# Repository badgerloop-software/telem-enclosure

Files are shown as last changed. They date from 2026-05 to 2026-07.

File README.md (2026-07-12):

# Telemetry Enclosure

<p align="center">
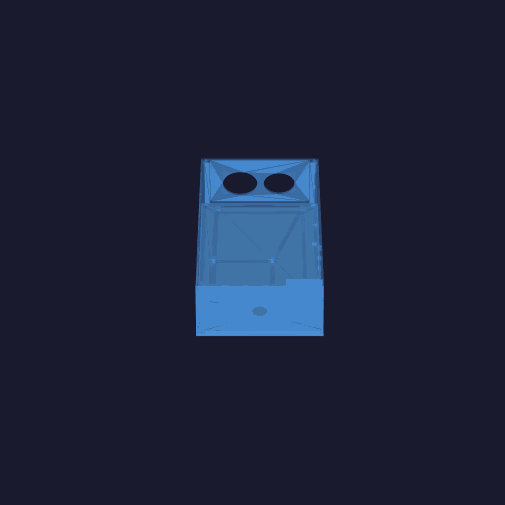
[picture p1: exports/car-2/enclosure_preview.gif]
Car 2 enclosure preview
  
</p>
3D-printable enclosure for an airborne / ground-station telemetry stack:

| Component | Notes |
|---|---|
| Raspberry Pi 4B | Bottom layer, M2.5 standoffs |
| RFD900A telemetry radio | Adhesive-mounted to left interior wall |
| Quectel EG25-G LTE module | 4× M3 wall-boss screws via Mini PCIe-to-USB adapter |
| Adafruit DS3231 RTC | Sits directly on Pi GPIO pins (no separate mount) |

| Version | Dimensions (L × W × H) | Role |
|---|---|---|
| **car-2** (active) | 228.6 × 223.5 × 57.2 mm | Working redesign — edit these exports |
| **car-1.5** (archive) | 228.6 × 223.5 × 57.2 mm | Pristine recovered SolidWorks 2023 STEP baseline |

Printable in PLA or PETG. See [`exports/README.md`](exports/README.md) for file layout.

---

## Repository layout

```
README.md                        ← you are here
telem-enclosure-components.pdf   ← component datasheets / spec reference
cad/
  import_legacy.py        ← import car-1.5 STEP → exports/car-1.5/
  analyze_step.py         ← inspect bounding boxes and hole sizes
  render_gif.py           ← turntable GIF (arg: car-1.5 or car-2)
  smooth_floor.py         ← car-2 interior floor cleanup (from car-1.5 baseline)
  update_assembly.py      ← rebuild telem_enclosure_assembly.FCStd after body/lid edits
  face_templates.py       ← 1:1 print templates (legacy compact layout)
  enclosure.py / params.py  ← experimental compact parametric model (not current car-2)
  README.md               ← design notes and print settings
exports/
  README.md               ← version layout guide
  car-1.5/                ← recovered SolidWorks archive (do not edit)
  car-2/                  ← active working folder (legacy-based redesign)
viewer/                   ← lightweight STL web viewer (face select, no FreeCAD GUI)
  server.py
  static/                 ← Three.js UI
tools/
  freecad-mcp/          ← contextform/freecad-mcp bridge for Cursor MCP
  render-venv/          ← gitignored Python venv for render_gif.py
  FreeCAD.AppImage      ← gitignored (download separately, see below)
  squashfs-root/        ← gitignored (extracted AppImage runtime)
.cursor/
  mcp.json              ← FreeCAD MCP server config for Cursor
```

## Quick start

1. **Get FreeCAD 1.0+** — either via apt or AppImage:
   ```bash
   sudo apt install freecad          # Ubuntu / Debian
   # or download the AppImage from https://freecad.org/downloads.php
   # and place it at tools/FreeCAD.AppImage
   ```

2. **Regenerate the car-1.5 archive** (only if source STEP files changed):
   ```bash
   echo 'exec(open("cad/import_legacy.py").read())' | \
     ./tools/squashfs-root/usr/bin/freecadcmd
   ```
   Reads `exports/car-1.5/SoftwareEnclosure*Car1.5.STEP`, aligns the body to
   origin, and writes `enclosure_body.{FCStd,step,stl}`, `enclosure_lid.*`, and
   `telem_enclosure_assembly.FCStd` into `exports/car-1.5/`.

3. **Work in `exports/car-2/`** — the active redesign. Copy fresh exports from
   `car-1.5/` when resetting, then edit `enclosure_body.{FCStd,step,stl}` (and lid
   as needed) in FreeCAD GUI or via the MCP bridge below.

4. **Regenerate the README preview GIF** after car-2 changes:
   ```bash
   tools/render-venv/bin/python cad/render_gif.py car-2
   ```

5. **Sync the FreeCAD assembly** after body or lid STEP/STL changes:
   ```bash
   ./tools/squashfs-root/usr/bin/freecadcmd cad/update_assembly.py car-2
   ```

See [`cad/README.md`](cad/README.md) for design notes and print settings.

## Web viewer (STL + face IDs)

A lightweight browser viewer lives in [`viewer/`](viewer/) — useful for inspecting
exports without opening FreeCAD.

```bash
python3 viewer/server.py
# open http://127.0.0.1:8765
```

| Feature | Notes |
|---|---|
| Model picker | All `exports/**/*.stl` (defaults to `car-2/enclosure_body.stl`) |
| Auto-reload | Polls file mtime every 1.5 s when STL on disk changes |
| Face IDs | First click on a flat patch assigns **#1, #2, …**; reuse when re-selected |
| Orientation | Body sits on its bottom face; **+X / +Y / +Z** axis labels on the grid |
| Save | Writes binary STL back to `exports/` (creates `.bak` first) |

**Regenerate body exports** (smooth interior floor, etc.):

```bash
./tools/squashfs-root/usr/bin/freecadcmd cad/smooth_floor.py
./tools/squashfs-root/usr/bin/freecadcmd cad/update_assembly.py car-2
```

The viewer reloads automatically when `enclosure_body.stl` changes.

## Working with Google Antigravity

Use the viewer and chat together so you can point at geometry by name:

1. **Start the viewer** (`python3 viewer/server.py`) and open the car-2 body STL.
2. **Click faces** in the model — each gets a stable number in the sidebar (e.g. **Face #2**).
3. **Tell the agent** what to change using those IDs: *“smooth face #2”*, *“remove bosses above face #3”*, etc.
4. The agent edits CAD scripts (e.g. `cad/smooth_floor.py`) or drives **FreeCAD MCP** (below), re-exports STEP/STL, and the viewer picks up the new mesh.

For live boolean edits in FreeCAD GUI, use the MCP bridge. For quick visual review and
face naming, use the web viewer — no FreeCAD window required.

## Antigravity MCP (drive FreeCAD from chat)

The repo ships a `.cursor/mcp.json` pointing to the bundled `freecad-mcp` bridge. You can add this configuration to your Antigravity setup to use it.

1. Install the Python `mcp` package (already done if you cloned this repo with the venv):
   ```bash
   cd tools/freecad-mcp && python3 -m venv .venv && .venv/bin/pip install mcp
   ```
2. In Antigravity: **add the MCP server** — a `freecad` server should appear.
3. Launch FreeCAD GUI, open `exports/car-2/enclosure_body.FCStd` or `enclosure_lid.FCStd`,
   then ask the agent to make changes; it drives FreeCAD live over the Unix socket.

## Printing

| | Body | Lid |
|---|---|---|
| Material | PETG (preferred) or PLA | PETG or PLA |
| Layer height | 0.2 mm | 0.2 mm |
| Infill | 20% gyroid | 20% gyroid |
| Walls | 3 perimeters | 3 perimeters |
| Supports | Tree — I/O cutouts only | None |
| Orientation | Open side up | Top face down |

Use M2.5 brass heat-set inserts in the Pi standoffs and lid-corner screw bosses  
for reusability. M3 × 6 mm self-tappers secure the Quectel adapter to its posts.

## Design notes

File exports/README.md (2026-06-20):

# Exports by car version

All generated model files are grouped by vehicle generation.

## `car-2/` — active redesign (work here)

| File | Description |
|---|---|
| `enclosure_body.{FCStd,step,stl}` | Body — legacy car-1.5 geometry with redesign edits |
| `enclosure_lid.{FCStd,step,stl}` | Lid copied from car-1.5 baseline |
| `telem_enclosure_assembly.FCStd` | Body + lid preview |
| `enclosure_preview.gif` | Turntable animation (shown in root README) |
| `face_templates.pdf` | Legacy 1:1 fit-check sheets (compact parametric layout; may not match) |

**Extents:** 228.6 × 223.5 × 57.2 mm (body + lid)

**Current edits:** interior floor smoothed — square pocket cutouts removed, Pi standoff
bosses and mounting holes filled (flat floor at z = 7.62 mm).

Regenerate after floor edits:
```bash
./tools/squashfs-root/usr/bin/freecadcmd cad/smooth_floor.py
./tools/squashfs-root/usr/bin/freecadcmd cad/update_assembly.py car-2
tools/render-venv/bin/python cad/render_gif.py car-2
```

**Web viewer** — inspect STL, assign face numbers for AI chat, save back to disk:
```bash
python3 viewer/server.py
# open http://127.0.0.1:8765 — select faces, reference them as #1, #2, … in Cursor
```
Auto-reload picks up STL changes when you re-export from CAD scripts. See root
[`README.md`](../README.md) for the full viewer + Cursor workflow.

**Reset from archive** (copies pristine car-1.5 exports into car-2):
```bash
cp exports/car-1.5/enclosure_body.{FCStd,step,stl} exports/car-2/
cp exports/car-1.5/enclosure_lid.{FCStd,step,stl} exports/car-2/
cp exports/car-1.5/telem_enclosure_assembly.FCStd exports/car-2/
```

## `car-1.5/` — recovered SolidWorks archive (read-only baseline)

| File | Description |
|---|---|
| `SoftwareEnclosureBottomCar1.5.STEP` | Original SolidWorks body (source) |
| `SoftwareEnclosureTopCar1.5.STEP` | Original SolidWorks lid (source) |
| `enclosure_body.{FCStd,step,stl}` | Body aligned to origin via `cad/import_legacy.py` |
| `enclosure_lid.{FCStd,step,stl}` | Lid (already origin-aligned) |
| `telem_enclosure_assembly.FCStd` | Body + lid preview |

**Extents:** 228.6 × 223.5 × 57.2 mm (body + lid)

Regenerate from source STEP:
```bash
echo 'exec(open("cad/import_legacy.py").read())' | ./tools/squashfs-root/usr/bin/freecadcmd
```

## Experimental compact parametric model

`cad/enclosure.py` builds a separate 116 × 86 mm enclosure into `exports/car-2/` if run
directly — that workflow is **not** the current car-2 redesign. Do not run it unless you
intend to replace the legacy-based exports.

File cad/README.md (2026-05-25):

# Compact Telemetry Enclosure

Parametric 3D-printable enclosure for:

- Raspberry Pi 4B
- RFD900A telemetry radio
- Quectel EG25-G LTE module (USB)
- Adafruit RTC (CR1220 onboard)

All dimensions in `cad/params.py`. The build script `cad/enclosure.py`
generates two STEP + STL files (body and lid) and an assembly preview into
`exports/`.

## Layout

```
                   +Y (back, long wall)
                   +-----------------------------+
                   | [GPIO pass-through]         |
                   |     Quectel rail + posts    |
                   |   ___________________       |
                   |  |                   |      |
    RFD900A (VHB)  |  |  Pi 4B (corner)   | Eth/ |
    on left wall → |  |  long edge along  | USB  |  +X
                   |  |  X axis           |      |
                   |  |___________________|      |
                   |                             |
                   | RTC                         |
                   +-----------------------------+
                   -Y (front long wall, HDMI/USB-C/audio cutout)
                                     |
                                  +X end (Eth + 2x USB-A cutout)
```

The Raspberry Pi sits in the +X / -Y interior corner so two of its I/O edges
are flush against the body walls.

### RFD900A mounting

The RFD900A (53 × 33 × 12 mm) has no PCB mounting holes, so it is
**adhesive-mounted** to the flat interior face of the left short wall (X = 0
inside), using VHB or double-sided foam tape. The model has no structural
features for it — the interior wall face is left smooth. Orient the board
with its antenna connectors toward the lid and U.FL cables routed up through
the lid antenna holes.

## Dimensions (default)

| Quantity | Value |
| --- | --- |
| Internal cavity | 112 x 82 x 50 mm |
| External (body+lid) | 116 x 86 x ~55.5 mm |
| Wall thickness | 2.0 mm |
| Floor thickness | 2.5 mm |
| Lid thickness | 3.0 mm |
| Pi standoff height | 12 mm (M2.5 self-tap) |
| Upper shelf height | 36 mm above interior floor |
| Antenna holes | 5 x diameter 7.0 mm (3 LTE + 2 RFD) |
| Lid corner screws | 4 x M2.5 self-tap |

> The original spec called external height of 54.5 mm. Since wall=2, floor=2.5
> and lid=3, total external height with a flush lid is `2.5 + 50 + 3 = 55.5 mm`.
> Adjust `INT_H`, `FLOOR`, or `LID` in `params.py` if you need exactly 54.5 mm.

## Generate the model

Requires FreeCAD 1.0 or later (provides `freecadcmd` and the `Part`/`Mesh`
Python modules).

```bash
freecadcmd cad/enclosure.py
```

This writes into `exports/`:

- `enclosure_body.FCStd` / `.step` / `.stl`
- `enclosure_lid.FCStd`  / `.step` / `.stl`
- `telem_enclosure_assembly.FCStd` (body + lid + transparent reference bricks
  for Pi, RFD900A, Quectel, RTC)

If you only have the FreeCAD AppImage extracted at `tools/FreeCAD.AppImage`:

```bash
./tools/FreeCAD.AppImage --console cad/enclosure.py
# or, if extracted:
./tools/squashfs-root/AppRun --console cad/enclosure.py
```

## Driving FreeCAD from Cursor (MCP)

The repo ships `.cursor/mcp.json` configured for the
[contextform/freecad-mcp](https://github.com/contextform/freecad-mcp) bridge.
Once installed at `~/tools/freecad-mcp/` you can describe changes in chat and
the agent will manipulate the live FreeCAD document over MCP. The parametric
script remains the source of truth for regenerating from scratch.

## Print settings

| Setting | Body | Lid |
| --- | --- | --- |
| Material  | PETG (preferred) / PLA  | PETG / PLA |
| Layer | 0.2 mm | 0.2 mm |
| Infill | 20% gyroid | 20% gyroid |
| Walls | 3 perimeters | 3 perimeters |
| Supports  | Tree, only for I/O wall cutouts and standoff overhang | None (print snap-lip-down) |
| Orient | Open side up | Top face down |

Use M2.5 brass heat-set inserts in the standoffs and screw bosses for
reusability; if you don't have inserts, the default 2.1 mm pilot holes are
sized for M2.5 self-tappers in PETG.

## Tweaking the design

Common edits, all in `cad/params.py`:

- Change overall size: `INT_L`, `INT_W`, `INT_H`.
- Move the Pi off the corner: edit `PI_X0_INT`, `PI_Y0_INT`.
- Swap antenna group orientation: edit `ANT_LTE_Y_OFFSET`, `ANT_RFD_Y_OFFSET`,
  spacings or counts.
- Wider GPIO pass-through: `GPIO_PASS_W`, `GPIO_PASS_H`.
- More vent slots: `SIDE_VENT_COUNT_PER_LONG_WALL`, `LID_VENT_COUNT`.

Re-run `freecadcmd cad/enclosure.py`. The script also prints a clearance
report and warns if any component would collide with the lid or shelves.

## Component — Quectel adapter (Mini PCIe-to-USB)

SUPERPLUS adapter, actual dimensions: **88.9 × 44.96 × 18.03 mm**

4 mounting holes (3.55 mm Ø):
- Centre from each short (L-end) edge: 4.775 mm
- Centre from each long (W-edge) edge: 3.775 mm

The enclosure has 4 × M3 self-tap screw posts at these positions on the upper
shelf. The adapter rests on the posts and is secured with M3 × 6 mm screws.

## Verified clearances (from current params)

The build script prints a clearance report each run. Current numbers:

| Item | Z (world, mm) | Headroom (mm) |
| --- | --- | --- |
| Pi USB-A stack top | 33.0 | — |
| Shelf rail bottom | 34.5 | 1.5 above Pi  |
| RFD900A top (on shelf) | 49.5 | 8.0 to lid |
| Quectel adapter top (on shelf) | 55.5 | 2.0 to lid |
| RFD900A vs Quectel side gap | — | 4.0 mm |

`INT_H` is 55 mm (external body height ≈ 60.5 mm including floor + lid). If
your Quectel adapter ends up taller than 18 mm, increase `INT_H` by the
difference and rebuild.

## Known limitations / future work

- Component bays use simple side rails + a 4 mm retention nib; for shipping
  use, replace with screw-mount posts to whatever holes the RFD900A and
  Quectel adapter actually expose.
- Antenna hole layout is symmetric/centered; if specific antennas need to
  avoid the lid stiffener ribs, override coordinates in
  `antenna_hole_positions_exterior()`.
- GPIO access is via lid removal plus a single 18x8 mm pass-through slot on
  the back long wall. For a real panel-mount GPIO breakout, add a dedicated
  ribbon-cable cutout on the back long wall in `params.py`.
- Lid screw bosses hang from the top of the body walls (not from the floor),
  so they clear the Pi PCB sitting in the corner. They give ~10 mm of M2.5
  thread engagement.

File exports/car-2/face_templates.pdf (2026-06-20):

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

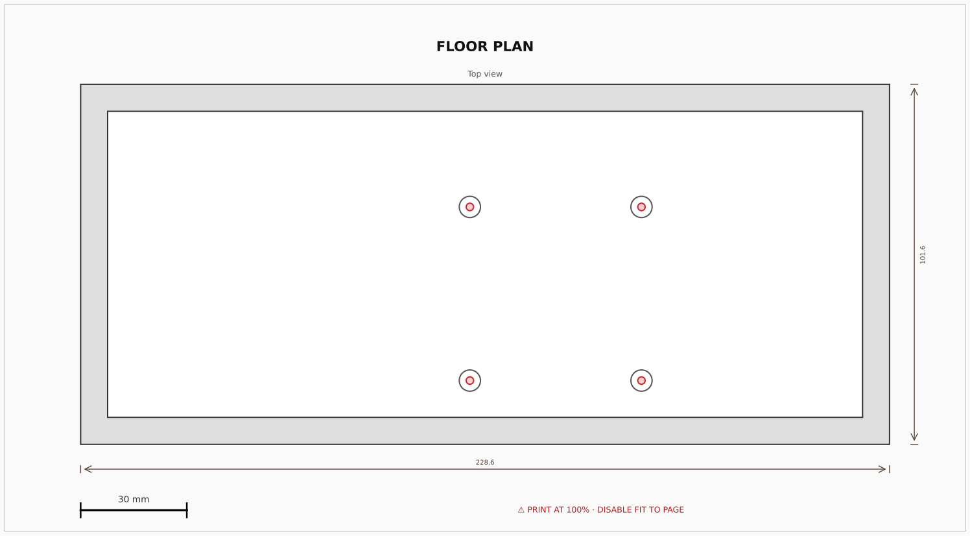
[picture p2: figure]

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

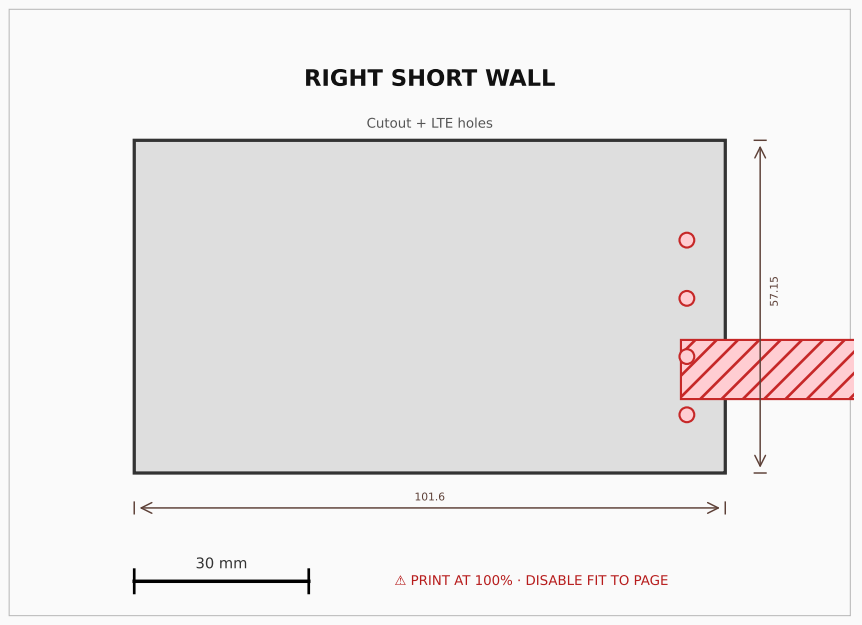
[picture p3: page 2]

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

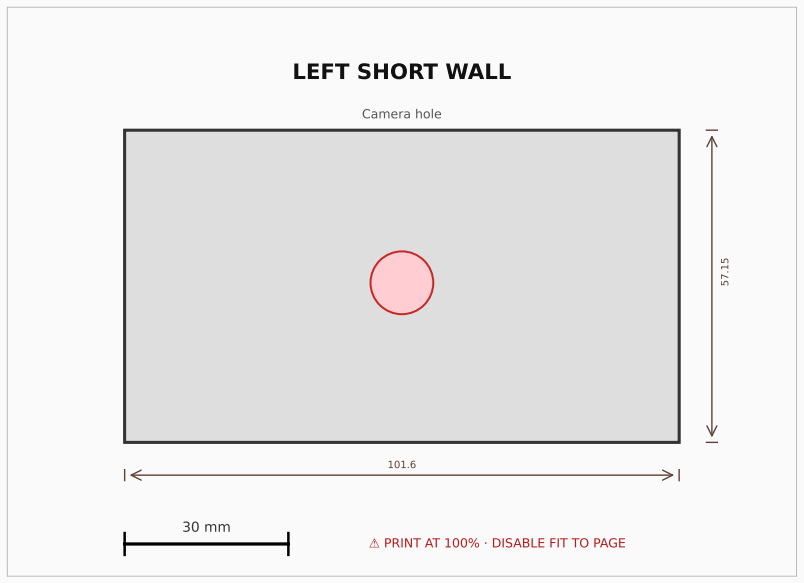
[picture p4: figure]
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

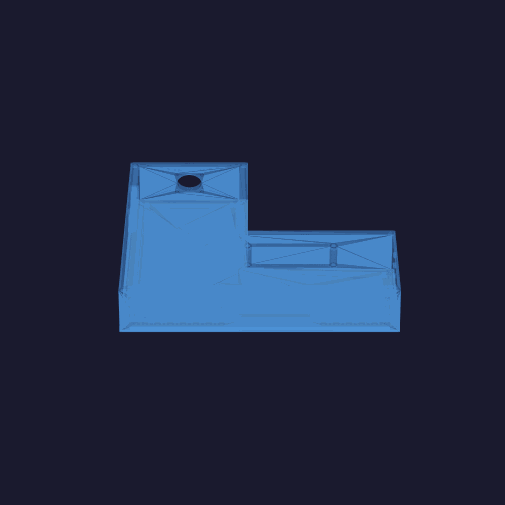
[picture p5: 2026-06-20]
preview_frame.png

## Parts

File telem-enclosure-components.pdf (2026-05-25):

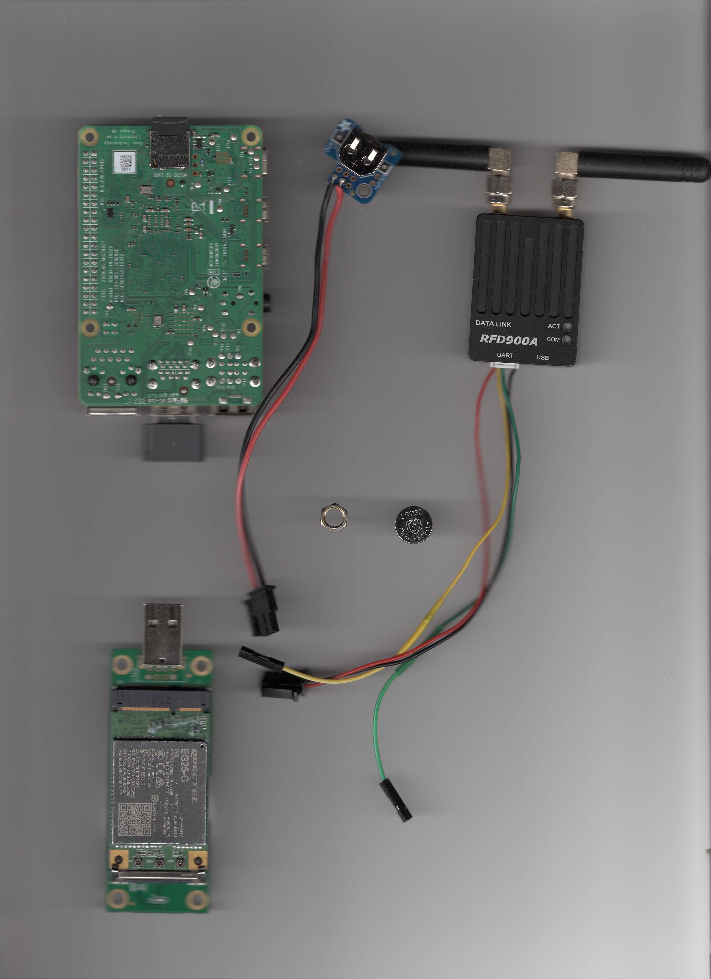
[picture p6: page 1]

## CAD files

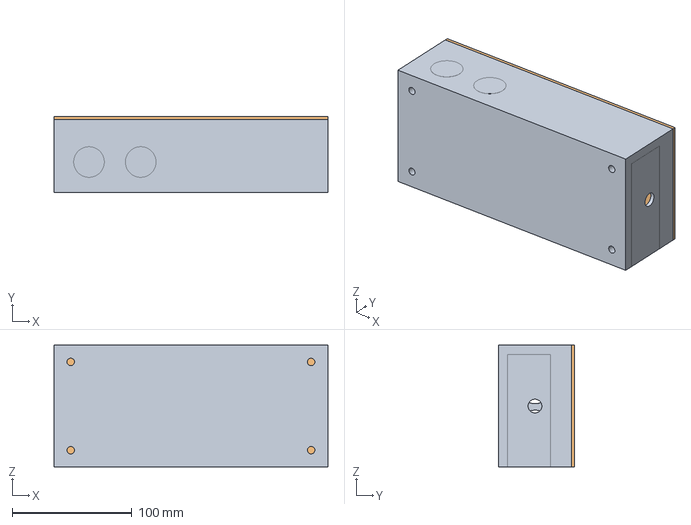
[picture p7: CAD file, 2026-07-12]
exports/car-2/telem_enclosure_assembly.FCStd
228.7 x 63.3 x 101.7 mm
Lid

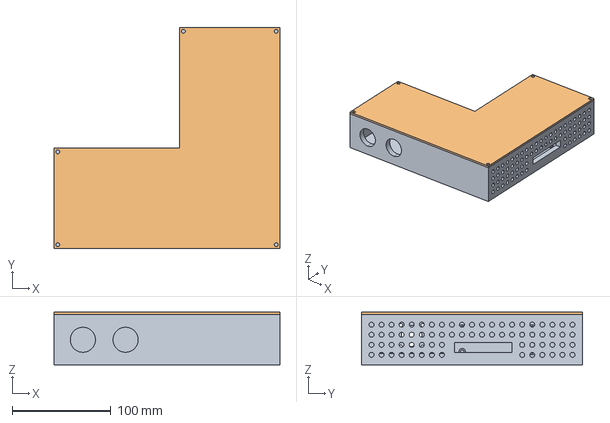
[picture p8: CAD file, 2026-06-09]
exports/car-1.5/telem_enclosure_assembly.FCStd
228.6 x 223.5 x 53.3 mm
Lid

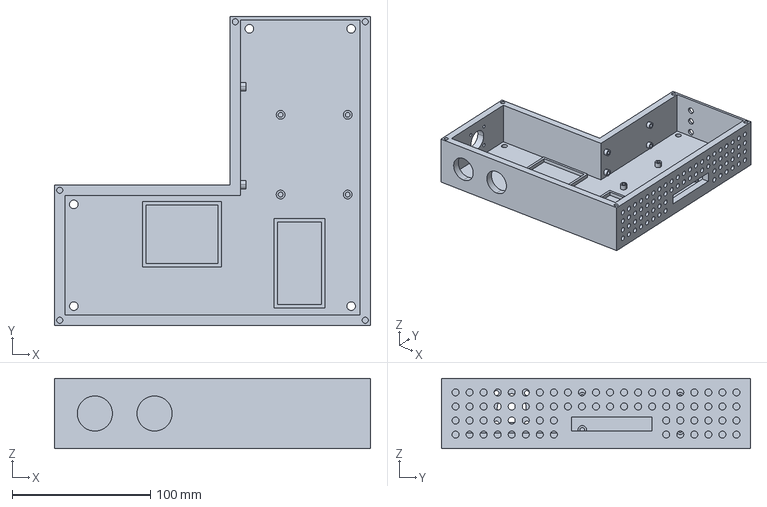
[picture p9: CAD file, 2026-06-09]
exports/car-1.5/enclosure_body.step
228.6 x 223.5 x 50.8 mm

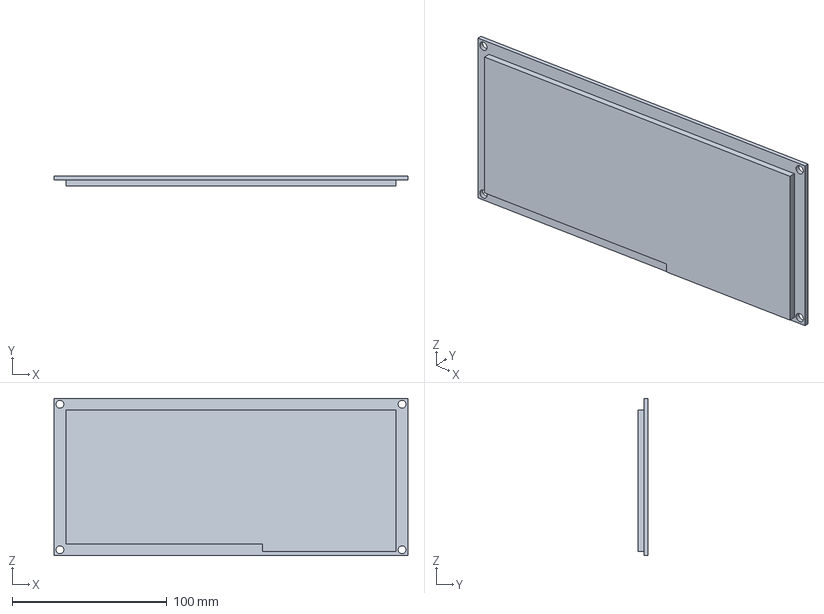
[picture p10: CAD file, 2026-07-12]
exports/car-2/enclosure_lid.step
228.6 x 6.35 x 101.6 mm

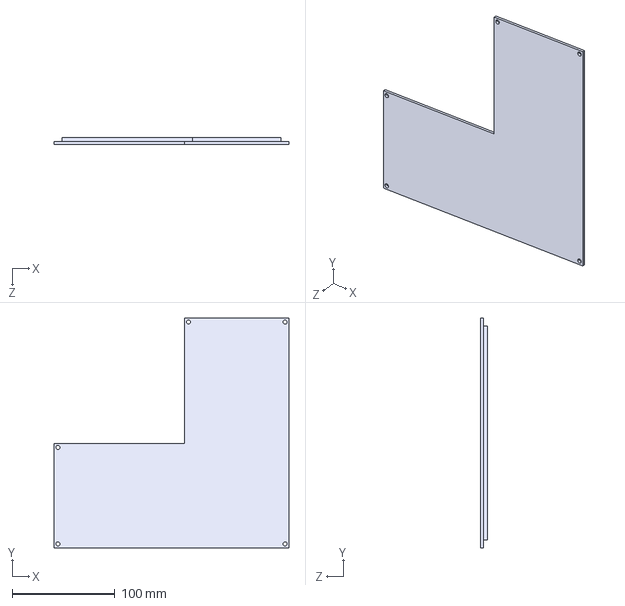
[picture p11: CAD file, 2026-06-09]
exports/car-1.5/SoftwareEnclosureTopCar1.5.STEP
228.6 x 223.5 x 6.35 mm

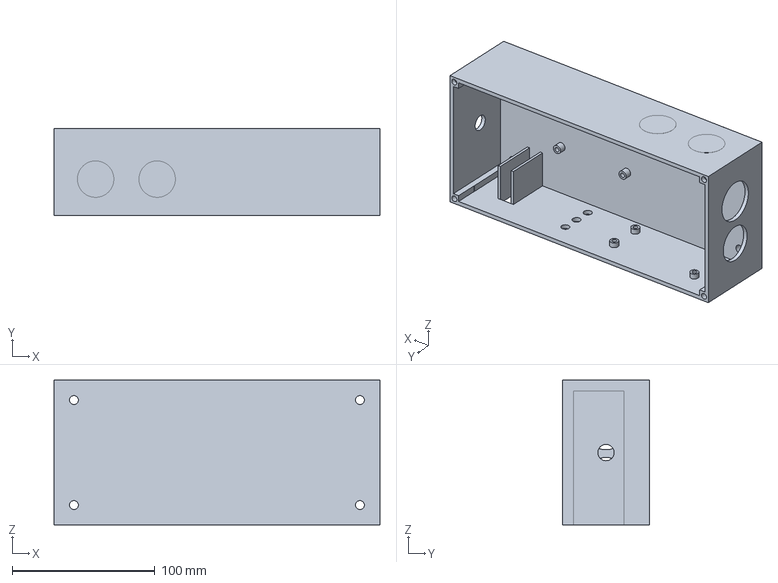
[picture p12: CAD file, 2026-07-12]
exports/car-2/enclosure_body.step
228.7 x 60.8 x 101.7 mm

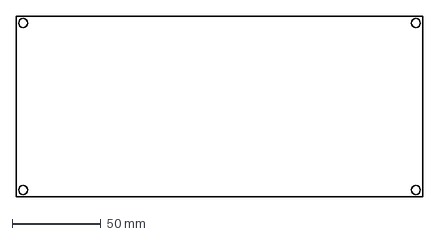
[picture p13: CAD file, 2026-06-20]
exports/car-2/enclosure_lid_flat.dxf
228.6 x 101.6 mm

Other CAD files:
exports/car-1.5/SoftwareEnclosureBottomCar1.5.STEP
exports/car-2/enclosure_body_head.stl
exports/car-1.5/enclosure_lid.step
exports/car-2/temp_relocated.step
exports/car-1.5/enclosure_body.FCStd
exports/car-1.5/enclosure_body.stl
exports/car-1.5/enclosure_lid.FCStd
exports/car-1.5/enclosure_lid.stl
exports/car-2/enclosure_body.FCStd
exports/car-2/enclosure_body.stl
exports/car-2/enclosure_lid.FCStd
exports/car-2/enclosure_lid.stl
exports/car-2/telem_enclosure_assembly.stl

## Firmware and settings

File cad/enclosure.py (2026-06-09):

"""Build the compact telemetry enclosure (body + lid) in FreeCAD.

Run headless from the project root:

    freecadcmd cad/enclosure.py

Or open FreeCAD GUI -> Macro -> open this file and run.

Outputs into ../exports/car-2 relative to this file:
    enclosure_body.FCStd, enclosure_body.step, enclosure_body.stl
    enclosure_lid.FCStd,  enclosure_lid.step,  enclosure_lid.stl
    telem_enclosure_assembly.FCStd  (body + lid + reference component bricks)
"""

from __future__ import annotations

import os
import sys
from pathlib import Path

import FreeCAD as App
import Part
import Mesh

# Make `params` importable when run via freecadcmd or exec()
try:
    HERE = Path(__file__).resolve().parent
except NameError:
    cwd = Path.cwd().resolve()
    HERE = cwd / "cad" if (cwd / "cad" / "params.py").exists() else cwd
if str(HERE) not in sys.path:
    sys.path.insert(0, str(HERE))

import params as P  # noqa: E402


EXPORT_DIR = HERE.parent / "exports" / "car-2"
EXPORT_DIR.mkdir(parents=True, exist_ok=True)


# ----------------------------------------------------------------------------
# Helpers
# ----------------------------------------------------------------------------

def _box(x, y, z, dx, dy, dz):
    """Axis-aligned box positioned at (x,y,z) with size (dx,dy,dz)."""
    b = Part.makeBox(dx, dy, dz)
    b.translate(App.Vector(x, y, z))
    return b


def _cyl(x, y, z, d, h, dir_=(0, 0, 1)):
    c = Part.makeCylinder(d / 2.0, h, App.Vector(x, y, z), App.Vector(*dir_))
    return c


def _interior_to_exterior(x, y, z):
    """Convert an interior-frame point (X in 0..INT_L, Y in 0..INT_W, Z above
    interior floor) into the body's exterior frame used by Part shapes."""
    return (x + P.WALL, y + P.WALL, z + P.FLOOR)


def _slot(x_center, y_center, z_center, length_x, length_y, length_z):
    """Centered axis-aligned box for cutouts."""
    return _box(
        x_center - length_x / 2.0,
        y_center - length_y / 2.0,
        z_center - length_z / 2.0,
        length_x,
        length_y,
        length_z,
    )


# ----------------------------------------------------------------------------
# Body
# ----------------------------------------------------------------------------

def build_body() -> Part.Shape:
    """Construct the enclosure body shell with standoffs, shelves and cutouts."""

    # Outer block, then carve cavity from the top to leave the floor.
    outer = _box(0, 0, 0, P.EXT_L, P.EXT_W, P.BODY_H)
    cavity = _box(P.WALL, P.WALL, P.FLOOR,
                  P.INT_L, P.INT_W, P.INT_H + P.LID + 1.0)
    body = outer.cut(cavity)

    # ---- Pi standoffs ----
    standoff_solids = []
    standoff_holes = []
    for ix, iy in P.pi_hole_positions_interior():
        ex, ey, _ = _interior_to_exterior(ix, iy, 0)
        standoff_solids.append(
            _cyl(ex, ey, P.FLOOR, P.STANDOFF_OD, P.STANDOFF_H)
        )
        standoff_holes.append(
            _cyl(ex, ey,
                 P.FLOOR + P.STANDOFF_H - P.STANDOFF_HOLE_DEPTH,
                 P.STANDOFF_HOLE_D,
                 P.STANDOFF_HOLE_DEPTH + P.EPS)
        )
    for s in standoff_solids:
        body = body.fuse(s)
    for h in standoff_holes:
        body = body.cut(h)

    # ---- Lid screw bosses (hang from top of body walls so they don't
    # collide with the Pi PCB sitting in the +X/-Y corner) ----
    boss_h = 10.0           # how far the boss hangs down from the wall top
    cavity_vol = _box(P.WALL, P.WALL, P.FLOOR,
                      P.INT_L, P.INT_W, P.INT_H)
    for sx, sy in P.lid_screw_positions_exterior():
        boss = _cyl(sx, sy, P.BODY_H - boss_h,
                    P.LID_SCREW_BOSS_OD, boss_h)
        boss_in = boss.common(cavity_vol)
        body = body.fuse(boss_in)
        # Self-tap pilot hole, drilled from the top
        hole = _cyl(sx, sy, P.BODY_H - boss_h - P.EPS,
                    P.LID_SCREW_BOSS_HOLE_D, boss_h + 2 * P.EPS)
        body = body.cut(hole)

    # ---- Quectel adapter: wall-mount bosses on back wall interior face ----
    # The adapter PCB sits flat against the back wall, held on 4 standoff
    # bosses (QU_MOUNT_POST_H = 3 mm) with M3 self-tap screws through the PCB.
    # Bosses project in the -Y direction from Y = WALL+INT_W.
    back_wall_y = P.WALL + P.INT_W
    for ix, iz in P.quectel_wall_hole_positions():
        ex = P.WALL + ix
        ez = P.FLOOR + iz
        boss = _cyl(ex, back_wall_y, ez,
                    P.QU_MOUNT_POST_OD, P.QU_MOUNT_POST_H, dir_=(0, -1, 0))
        body = body.fuse(boss)
        # Pilot drilled inward from the interior face (deeper than the boss)
        pilot = _cyl(ex, back_wall_y + P.EPS, ez,
                     P.QU_MOUNT_PILOT_D, P.QU_MOUNT_PILOT_DEPTH, dir_=(0, -1, 0))
        body = body.cut(pilot)

    # RTC mounts directly on Pi GPIO pins — no enclosure platform.

    # ---- Pi I/O cutout: media long edge on Y=0 wall ----
    media_z_min = P.FLOOR + P.MEDIA_CUTOUT_Z_MIN
    media_z_max = P.FLOOR + P.MEDIA_CUTOUT_Z_MAX
    media_dz = media_z_max - media_z_min
    pi_x_world = P.WALL + P.PI_X0_INT
    # Single combined slot covering USB-C through audio jack (X-range).
    media_x_min = pi_x_world + P.PI_USBC_X[0] - P.MEDIA_CUTOUT_PAD_X
    media_x_max = pi_x_world + P.PI_AUDIO_X[1] + P.MEDIA_CUTOUT_PAD_X
    media_cutout = _box(
        media_x_min, -P.EPS, media_z_min,
        media_x_max - media_x_min,
        P.WALL + 2 * P.EPS,
        media_dz,
    )
    body = body.cut(media_cutout)

    # ---- Pi I/O cutout: network short edge on X=INT_L wall (right) ----
    net_z_min = P.FLOOR + P.NET_CUTOUT_Z_MIN
    net_z_max = P.FLOOR + P.NET_CUTOUT_Z_MAX
    pi_y_world = P.WALL + P.PI_Y0_INT
    net_y_min = pi_y_world + P.PI_NETPORT_Y[0] - P.NET_CUTOUT_Y_PAD
    net_y_max = pi_y_world + P.PI_NETPORT_Y[1] + P.NET_CUTOUT_Y_PAD
    net_cutout = _box(
        P.WALL + P.INT_L - P.EPS,
        net_y_min,
        net_z_min,
        P.WALL + 2 * P.EPS,
        net_y_max - net_y_min,
        net_z_max - net_z_min,
    )
    body = body.cut(net_cutout)

    # ---- GPIO wire pass-through on X=INT_L wall (right short wall) ----
    # Sits below the Pi network/USB cutout, centered on the same Y span.
    gpio_y_world = P.WALL + P.GPIO_PASS_Y_CENTER_INT
    gpio_z_world = P.FLOOR + P.GPIO_PASS_Z
    gpio_cutout = _slot(
        P.WALL + P.INT_L + P.WALL / 2.0,  # centered through the right wall
        gpio_y_world,
        gpio_z_world,
        P.WALL + 2 * P.EPS,
        P.GPIO_PASS_W,
        P.GPIO_PASS_H,
    )
    body = body.cut(gpio_cutout)

    # ---- Side vent slots on long walls ----
    for wall_y, dir_y in [(0.0, -1.0), (P.EXT_W, 1.0)]:
        spacing = P.EXT_L / (P.SIDE_VENT_COUNT_PER_LONG_WALL + 1)
        for i in range(1, P.SIDE_VENT_COUNT_PER_LONG_WALL + 1):
            cx = i * spacing
            cz = P.FLOOR + P.SIDE_VENT_Z_CENTER
            slot = _slot(
                cx,
                wall_y + dir_y * P.WALL / 2.0,
                cz,
                P.SIDE_VENT_L,
                P.WALL + 2 * P.EPS,
                P.SIDE_VENT_W,
            )
            body = body.cut(slot)

    # ---- Left short wall (X = 0): 3 LTE + 2 RFD SMA holes + 1 CAN port ----
    # LTE — vertical stack, near back edge
    for ay_w, az_w in P.lte_left_wall_positions():
        body = body.cut(_cyl(-P.EPS, ay_w, az_w,
                             P.ANT_HOLE_D, P.WALL + 2 * P.EPS, dir_=(1, 0, 0)))
    # RFD900A — vertical stack, 20 mm apart, near front edge
    for ay_w, az_w in P.rfd_left_wall_positions():
        body = body.cut(_cyl(-P.EPS, ay_w, az_w,
                             P.ANT_HOLE_D, P.WALL + 2 * P.EPS, dir_=(1, 0, 0)))
    # CAN port — larger hole in the centre of the wall
    body = body.cut(_cyl(-P.EPS, P.CAN_HOLE_Y_WORLD, P.CAN_HOLE_Z_WORLD,
                         P.CAN_HOLE_D, P.WALL + 2 * P.EPS, dir_=(1, 0, 0)))

    # ---- Chamfer outer bottom edge for printability/feel (1 mm) ----
    try:
        edges = []
        for e in body.Edges:
            verts = e.Vertexes
            if len(verts) < 2:
                continue
            if all(abs(v.Z) < 0.01 for v in verts):
                edges.append(e)
        if edges:
            body = body.makeChamfer(1.0, edges)
    except Exception as exc:  # noqa: BLE001
        App.Console.PrintWarning(f"Skip bottom chamfer: {exc}\n")

    return body


# ----------------------------------------------------------------------------
# Lid
# ----------------------------------------------------------------------------

def build_lid() -> Part.Shape:
    """Construct the lid plate with antenna holes, snap lip and screw holes.

    The lid is built in its own coordinate frame with origin at its outer
    bottom-front-left corner. When mounted, this corner aligns with
    (0, 0, BODY_H) of the body.
    """

    plate = _box(0, 0, 0, P.EXT_L, P.EXT_W, P.LID)

    # Snap lip projecting downward from the underside of the plate.
    lip_inner = _box(
        P.WALL + P.LID_LIP_GAP,
        P.WALL + P.LID_LIP_GAP,
        -P.LID_LIP_DEPTH,
        P.INT_L - 2 * P.LID_LIP_GAP,
        P.INT_W - 2 * P.LID_LIP_GAP,
        P.LID_LIP_DEPTH,
    )
    lip_outer = _box(
        P.WALL + P.LID_LIP_GAP - P.LID_LIP_T,
        P.WALL + P.LID_LIP_GAP - P.LID_LIP_T,
        -P.LID_LIP_DEPTH,
        P.INT_L - 2 * P.LID_LIP_GAP + 2 * P.LID_LIP_T,
        P.INT_W - 2 * P.LID_LIP_GAP + 2 * P.LID_LIP_T,
        P.LID_LIP_DEPTH,
    )
    lip = lip_outer.cut(lip_inner)
    lid = plate.fuse(lip)

    # Antenna holes are on the body walls, not the lid.

    # ---- Lid screw clearance holes at corners ----
    for sx, sy in P.lid_screw_positions_exterior():
        hole = _cyl(sx, sy, -P.EPS, P.LID_SCREW_CLEAR_D, P.LID + 2 * P.EPS)
        lid = lid.cut(hole)

    # ---- Lid vent slots ----
    spacing = P.EXT_L / (P.LID_VENT_COUNT + 1)
    for i in range(1, P.LID_VENT_COUNT + 1):
        cx = i * spacing
        cy = P.EXT_W / 2.0
        slot = _slot(cx, cy, P.LID / 2.0,
                     P.LID_VENT_W, P.LID_VENT_L, P.LID + 2 * P.EPS)
        lid = lid.cut(slot)

    return lid


# ----------------------------------------------------------------------------
# Reference component bricks (for assembly preview / clearance check only)
# ----------------------------------------------------------------------------

def reference_bricks():
    """Yield (label, shape) tuples in the BODY's exterior coordinate frame."""

    # Raspberry Pi 4B (PCB + tallest top-side components, ~20mm)
    pi_x = P.WALL + P.PI_X0_INT
    pi_y = P.WALL + P.PI_Y0_INT
    pi_z = P.FLOOR + P.PI_Z0_INT
    yield (
        "RPi4B",
        _box(pi_x, pi_y, pi_z, P.PI_L, P.PI_W, P.PI_PCB_T + P.PI_USBA_H + 1.0),
    )

    # RFD900A adhered to the left short wall interior face.
    # Show it lying flat against the wall (X=WALL is the inside face).
    rfd_x = P.WALL          # against the left interior wall face
    rfd_y = P.WALL + 5.0    # 5 mm in from front
    rfd_z = P.FLOOR + 10.0  # 10 mm above floor (clear of floor fillet)
    yield ("RFD900A_on_wall", _box(rfd_x, rfd_y, rfd_z, P.RFD_H, P.RFD_W, P.RFD_L))

    # Quectel + Mini PCIe adapter — back wall, PCB face at Y = back_wall - POST_H
    qu_pcb_y = P.WALL + P.INT_W - P.QU_MOUNT_POST_H
    qu_x = P.WALL + P.QU_WALL_X0_INT
    qu_z = P.FLOOR + P.QU_WALL_Z0_INT
    # Adapter: L along X, W along Z, H extends inward (-Y direction)
    yield ("Quectel_EG25-G", _box(qu_x, qu_pcb_y - P.QU_H, qu_z, P.QU_L, P.QU_H, P.QU_W))

    # Adafruit RTC mounts on Pi GPIO pins — no separate reference brick.


# ----------------------------------------------------------------------------
# Clearance reporting
# ----------------------------------------------------------------------------

def clearance_report(body_shape):
    """Print a quick numeric clearance report against the interior cavity."""
    print("\n=== Clearance check ===")
    cavity_top_z = P.FLOOR + P.INT_H
    print(f"Interior height above floor: {P.INT_H:.1f} mm "
          f"(floor Z={P.FLOOR}, lid underside Z={cavity_top_z})")
    pi_top_z = P.FLOOR + P.PI_Z0_INT + P.PI_PCB_T + P.PI_USBA_H
    print(f"Pi USB-A stack top Z: {pi_top_z:.1f} mm "
          f"(headroom to lid: {cavity_top_z - pi_top_z:.1f} mm)")
    # Quectel on back wall: spans Z from QU_WALL_Z0_INT to QU_WALL_Z0_INT+QU_W
    qu_z_top = P.FLOOR + P.QU_WALL_Z0_INT + P.QU_W
    qu_y_front = P.WALL + P.INT_W - P.QU_MOUNT_POST_H - P.QU_H
    pi_y_max_world = P.WALL + P.PI_W
    print(f"Quectel Z span: {P.FLOOR + P.QU_WALL_Z0_INT:.1f}–{qu_z_top:.2f} mm "
          f"(headroom: {cavity_top_z - qu_z_top:.2f} mm)")
    print(f"Quectel front face Y: {qu_y_front:.2f} mm, Pi Y edge: {pi_y_max_world:.1f} mm, "
          f"gap: {qu_y_front - pi_y_max_world:.2f} mm")
    if qu_y_front < pi_y_max_world:
        print("WARNING: Quectel front face overlaps Pi PCB in Y — increase INT_W or reduce QU_H.")
    if qu_z_top > cavity_top_z:
        print("WARNING: Quectel taller than interior. Increase INT_H.")
    rfd_wall_top_z = P.FLOOR + 10.0 + P.RFD_L
    print(f"RFD900A on left wall top Z: {rfd_wall_top_z:.1f} mm (adhesive, no structural feature)")
    print(f"LTE holes (left wall, back corner): {P.lte_left_wall_positions()}")
    print(f"RFD holes (left wall, front corner): {P.rfd_left_wall_positions()}")
    print(f"CAN hole (left wall, centre): Y={P.CAN_HOLE_Y_WORLD} Z={P.CAN_HOLE_Z_WORLD:.2f} D={P.CAN_HOLE_D}mm")
    print("=======================\n")


# ----------------------------------------------------------------------------
# Build and export
# ----------------------------------------------------------------------------

def _save_step(shape, path: Path):
    shape.exportStep(str(path))


def _save_stl(shape, path: Path):
    """Tessellate to mesh and export STL."""
    mesh = Mesh.Mesh()
    mesh.addFacets(shape.tessellate(0.1))
    mesh.write(str(path))


def main():
    body = build_body()
    lid = build_lid()

    clearance_report(body)

    # ---- Body document ----
    body_doc = App.newDocument("enclosure_body")
    body_obj = body_doc.addObject("Part::Feature", "Body")
    body_obj.Shape = body
    body_doc.recompute()
    body_doc.saveAs(str(EXPORT_DIR / "enclosure_body.FCStd"))
    _save_step(body, EXPORT_DIR / "enclosure_body.step")
    _save_stl(body, EXPORT_DIR / "enclosure_body.stl")
    App.closeDocument(body_doc.Name)

    # ---- Lid document ----
    lid_doc = App.newDocument("enclosure_lid")
    lid_obj = lid_doc.addObject("Part::Feature", "Lid")
    lid_obj.Shape = lid
    lid_doc.recompute()
    lid_doc.saveAs(str(EXPORT_DIR / "enclosure_lid.FCStd"))
    _save_step(lid, EXPORT_DIR / "enclosure_lid.step")
    _save_stl(lid, EXPORT_DIR / "enclosure_lid.stl")
    App.closeDocument(lid_doc.Name)

    # ---- Assembly preview (body + lid translated up + reference bricks) ----
    asm = App.newDocument("telem_enclosure_assembly")
    body_a = asm.addObject("Part::Feature", "Body")
    body_a.Shape = body

    lid_placed = lid.copy()
    lid_placed.translate(App.Vector(0, 0, P.BODY_H))
    lid_a = asm.addObject("Part::Feature", "Lid")
    lid_a.Shape = lid_placed

    for label, brick in reference_bricks():
        ref = asm.addObject("Part::Feature", f"REF_{label}")
        ref.Shape = brick
        # ViewObject only exists when the GUI is loaded; ignore in headless.
        view = getattr(ref, "ViewObject", None)
        if view is not None:
            try:
                view.Transparency = 70
            except Exception:  # noqa: BLE001
                pass

    asm.recompute()
    asm.saveAs(str(EXPORT_DIR / "telem_enclosure_assembly.FCStd"))
    App.closeDocument(asm.Name)

    print("\nWrote outputs to:", EXPORT_DIR)
    for p in sorted(EXPORT_DIR.iterdir()):
        print("  ", p.name, f"({p.stat().st_size // 1024} KB)")


if __name__ == "__main__":
    main()

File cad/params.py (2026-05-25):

"""Parametric dimensions for the compact telemetry enclosure.

All units are millimetres. Coordinate frame for the body:
    Origin at the OUTER bottom-front-left corner.
    +X = long axis (length)
    +Y = short axis (width)
    +Z = up (toward the lid)

The interior cavity therefore starts at (WALL, WALL, FLOOR) and ends at
(WALL + INT_L, WALL + INT_W, FLOOR + INT_H).

Edit any constant here and re-run `freecadcmd cad/enclosure.py` to regenerate
the model and STEP/STL exports.
"""

# ---------- Internal volume ----------
INT_L = 112.0   # X length, inside
INT_W = 82.0    # Y width, inside
INT_H = 55.0    # Z height, inside (floor top to lid underside)
                # Bumped from 50 → 55 to clear the 18 mm tall Quectel adapter

# ---------- Wall thicknesses ----------
WALL = 2.0      # side walls
FLOOR = 2.5     # bottom plate
LID = 3.0       # lid plate

# ---------- Derived externals ----------
EXT_L = INT_L + 2 * WALL    # 116
EXT_W = INT_W + 2 * WALL    # 86
BODY_H = FLOOR + INT_H      # 52.5 (without lid)
EXT_H = BODY_H + LID        # 55.5

# ---------- Raspberry Pi 4B ----------
PI_L = 85.6
PI_W = 56.5
PI_PCB_T = 1.5

# Pi 4B mounting hole pattern (4 holes, M2.5)
PI_HOLE_DX = 58.0           # along long edge
PI_HOLE_DY = 49.0           # along short edge
PI_HOLE_OFFSET = 3.5        # from each PCB edge to hole center

# Pi standoff geometry
STANDOFF_H = 12.0
STANDOFF_OD = 6.0
STANDOFF_HOLE_D = 2.1       # self-tap pilot for M2.5; use 3.6 for heat-set
STANDOFF_HOLE_DEPTH = 9.0

# Pi placement in the +X / -Y interior corner.
# Local-interior origin is (0,0,0) at the inside floor / front-left.
# Pi long edge along X. Pi short edge against X=INT_L (right short wall).
# Pi media long edge against Y=0 (front long wall).
PI_X0_INT = INT_L - PI_L    # 26.4 (x-coord of Pi's left short edge, inside)
PI_Y0_INT = 0.0             # Pi's media edge flush with front wall
PI_Z0_INT = STANDOFF_H      # Pi PCB bottom Z (above interior floor)

# ---------- Pi 4B I/O port positions (Pi-local, 0,0 at media/USB-C corner) ----------
# Long media edge ports (Pi_y == 0): cutout on the body's Y=0 wall.
PI_USBC_X    = (3.5, 13.0)
PI_HDMI0_X   = (20.0, 32.0)
PI_HDMI1_X   = (36.5, 48.5)
PI_AUDIO_X   = (52.5, 65.0)

# Network short edge ports (Pi_x == PI_L): cutout on the body's X=INT_L wall.
# Pi 4B has Ethernet + 2 USB-A stacks across the full short edge; one
# generous slot covers all three regardless of exact arrangement.
PI_NETPORT_Y = (1.5, 56.0)

# Port heights above PCB top
PI_USBA_H = 17.0
PI_ETH_H = 14.0
PI_HDMI_H = 6.5
PI_USBC_H = 3.5
PI_AUDIO_H = 6.5

# Z reference: top of Pi PCB above the interior floor
PCB_TOP_Z = PI_Z0_INT + PI_PCB_T  # 13.5

# ---------- I/O cutouts (interior coordinates, Z above interior floor) ----------
# Slight clearance around port footprints.
MEDIA_CUTOUT_Z_MIN = PCB_TOP_Z - 1.0    # 12.5
MEDIA_CUTOUT_Z_MAX = PCB_TOP_Z + 8.0    # 21.5
MEDIA_CUTOUT_PAD_X = 1.5                 # extra each side per port group

NET_CUTOUT_Z_MIN = PCB_TOP_Z - 1.0      # 12.5
NET_CUTOUT_Z_MAX = PCB_TOP_Z + 19.0     # 32.5
NET_CUTOUT_Y_PAD = 1.5

# GPIO wire pass-through — right short wall (X=INT_L), below the Pi I/O cutout.
# Centered on the same Y range as the Pi network port cutout, near the floor.
GPIO_PASS_W = 18.0
GPIO_PASS_H = 8.0
GPIO_PASS_Z = 6.0                        # interior Z of slot center (world Z = 8.5 mm)
GPIO_PASS_Y_CENTER_INT = (PI_NETPORT_Y[0] + PI_NETPORT_Y[1]) / 2.0  # ≈ 28.75 mm

# ---------- Vent slots ----------
SIDE_VENT_W = 2.0
SIDE_VENT_L = 30.0
SIDE_VENT_COUNT_PER_LONG_WALL = 4
SIDE_VENT_Z_CENTER = 40.0       # near the top of the cavity

LID_VENT_W = 2.0
LID_VENT_L = 20.0
LID_VENT_COUNT = 6

# ---------- Components ----------
# RFD900A — no PCB mounting holes, adhesive (VHB) to interior of left short wall
RFD_L = 53.0
RFD_W = 33.0
RFD_H = 12.0

# Mini PCIe-to-USB adapter (SUPERPLUS, 3.5" x 1.77" x 0.71")
# Mounted flat against the interior face of the back long wall (Y=INT_W).
# L runs along X, W runs along Z, H is the depth into the enclosure interior.
QU_L = 88.9     # 3.5 inches — runs along X
QU_W = 44.96    # 1.77 inches — runs along Z
QU_H = 18.03    # 0.71 inches — depth away from wall (into interior)

# Mounting holes: 3.55 mm dia, M3 self-tap bosses
# Center from each short (L-end) edge: 3 + hole_r = 4.775 mm  (along X)
# Center from each long  (W-edge) edge: 2 + hole_r = 3.775 mm  (along Z)
QU_HOLE_D = 3.55
QU_HOLE_FROM_L_END = 4.775
QU_HOLE_FROM_W_EDGE = 3.775
QU_MOUNT_POST_OD = 7.0
QU_MOUNT_POST_H = 3.0    # standoff height projecting from back wall face
QU_MOUNT_PILOT_D = 3.1   # M3 self-tap pilot in PETG
QU_MOUNT_PILOT_DEPTH = 8.0

# Quectel position on back wall (interior coords: left edge X, bottom edge Z)
QU_WALL_X0_INT = 10.0    # 10 mm from left interior wall
QU_WALL_Z0_INT = 8.0     # 8 mm above interior floor

# RTC sits directly on the Pi's GPIO pins — no enclosure platform needed.
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

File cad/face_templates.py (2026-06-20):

#!/usr/bin/env python3
from pathlib import Path
import matplotlib
matplotlib.use("Agg")
import matplotlib.pyplot as plt
from matplotlib.patches import Rectangle, Circle, FancyBboxPatch
from matplotlib.backends.backend_pdf import PdfPages

EXPORTS = Path(__file__).resolve().parent.parent / "exports" / "car-2"

# Page layout
MARGIN_X, MARGIN_Y, HDR, FTR = 22, 18, 14, 16
WALL_FC, WALL_EC = "#DEDEDE", "#333333"
CAVITY_FC = "#FFFFFF"
CUT_FC, CUT_EC = "#FFCDD2", "#C62828"
DIM_C, WARN_C = "#5D4037", "#B71C1C"

def _r(ax, x, y, w, h, fc=CAVITY_FC, ec=WALL_EC, lw=0.8, ls='-', hatch=None):
    kw = dict(facecolor=fc, edgecolor=ec, linewidth=lw, linestyle=ls)
    if hatch: kw['hatch'] = hatch
    ax.add_patch(Rectangle((x, y), w, h, **kw))

def _c(ax, cx, cy, d, fc=CUT_FC, ec=CUT_EC, lw=0.8):
    ax.add_patch(Circle((cx, cy), d / 2, facecolor=fc, edgecolor=ec, linewidth=lw))

def _txt(ax, x, y, text, size=4.5, color='#333', ha='center', va='center', **kw):
    ax.text(x, y, text, fontsize=size, color=color, ha=ha, va=va, **kw)

def _dim_h(ax, x1, x2, y, label):
    ax.annotate('', xy=(x2, y), xytext=(x1, y), arrowprops=dict(arrowstyle='<->', color=DIM_C, lw=0.55))
    for xp in (x1, x2): ax.plot([xp, xp], [y-1, y+1], color=DIM_C, lw=0.55)
    _txt(ax, (x1+x2)/2, y+1.8, label, size=4, color=DIM_C)

def _dim_v(ax, x, y1, y2, label):
    ax.annotate('', xy=(x, y2), xytext=(x, y1), arrowprops=dict(arrowstyle='<->', color=DIM_C, lw=0.55))
    for yp in (y1, y2): ax.plot([x-1, x+1], [yp, yp], color=DIM_C, lw=0.55)
    _txt(ax, x+2.5, (y1+y2)/2, label, size=4, color=DIM_C, rotation=90, rotation_mode='anchor', ha='left')

def _scale_bar(ax, x, y, length=30):
    ax.plot([x, x+length], [y, y], 'k-', lw=1.3)
    for xp in (x, x+length): ax.plot([xp, xp], [y-2, y+2], 'k-', lw=1.0)
    _txt(ax, x+length/2, y+3, f'{length} mm', size=5.5)

def make_page(pdf, title, subtitle, face_w, face_h, draw_fn):
    total_w = face_w + 2*MARGIN_X
    total_h = face_h + HDR + FTR + MARGIN_Y
    fig, ax = plt.subplots(figsize=(total_w/25.4, total_h/25.4))
    ax.set_aspect('equal')
    ax.axis('off')
    ax.set_xlim(0, total_w)
    ax.set_ylim(0, total_h)
    fig.patch.set_facecolor('#FAFAFA')
    ax.add_patch(FancyBboxPatch((0.5, 0.5), total_w-1, total_h-1, boxstyle="square,pad=0", edgecolor='#BBB', facecolor='none', lw=0.4))
    ox = MARGIN_X
    oy = FTR + MARGIN_Y/2
    draw_fn(ax, ox, oy, face_w, face_h)
    _txt(ax, total_w/2, oy+face_h+HDR*0.75, title, size=8.5, color='#111', fontweight='bold')
    _txt(ax, total_w/2, oy+face_h+HDR*0.2, subtitle, size=5, color='#555')
    _scale_bar(ax, MARGIN_X, FTR*0.4, 30)
    _txt(ax, total_w*0.62, FTR*0.4, "⚠ PRINT AT 100% · DISABLE FIT TO PAGE", size=5, color=WARN_C, ha='center')
    pdf.savefig(fig)
    plt.close(fig)

# DIMS
EXT_L = 228.6
EXT_W = 101.6
BODY_H = 57.15
WALL = 7.62

def draw_floor(ax, ox, oy, fw, fh):
    _r(ax, ox, oy, fw, fh, fc=WALL_FC)
    _r(ax, ox+WALL, oy+WALL, EXT_L-2*WALL, EXT_W-2*WALL, fc=CAVITY_FC)
    # Pi holes
    PI = [(110.0, 18.0), (110.0, 67.0), (158.5, 18.0), (158.5, 67.0)]
    for px, py in PI:
        _c(ax, ox+px, oy+py, 2.1)
        _c(ax, ox+px, oy+py, 6.0, fc='none', ec="#555")
    _dim_h(ax, ox, ox+fw, oy-7, f"{fw}")
    _dim_v(ax, ox+fw+7, oy, oy+fh, f"{fh}")

def draw_right_wall(ax, ox, oy, fw, fh):
    _r(ax, ox, oy, fw, fh, fc=WALL_FC)
    _r(ax, ox, oy, fw, fh, fc='none', ec=WALL_EC, lw=1.2)
    # Cutout
    _r(ax, ox+93.98, oy+12.7, 152.4-93.98, 22.86-12.7, fc=CUT_FC, ec=CUT_EC, hatch='///')
    # LTE bosses
    for iz in [10, 20, 30, 40]:
        _c(ax, ox+95.0, oy+iz, 2.54)
    _dim_h(ax, ox, ox+fw, oy-6, f"{fw}")
    _dim_v(ax, ox+fw+6, oy, oy+fh, f"{fh}")

def draw_left_wall(ax, ox, oy, fw, fh):
    _r(ax, ox, oy, fw, fh, fc=WALL_FC)
    _r(ax, ox, oy, fw, fh, fc='none', ec=WALL_EC, lw=1.2)
    # Camera hole
    _c(ax, ox+50.8, oy+29.21, 11.5)
    _dim_h(ax, ox, ox+fw, oy-6, f"{fw}")
    _dim_v(ax, ox+fw+6, oy, oy+fh, f"{fh}")

def main():
    EXPORTS.mkdir(parents=True, exist_ok=True)
    out = EXPORTS / "face_templates.pdf"
    with PdfPages(out) as pdf:
        make_page(pdf, "FLOOR PLAN", "Top view", EXT_L, EXT_W, draw_floor)
        make_page(pdf, "RIGHT SHORT WALL", "Cutout + LTE holes", EXT_W, BODY_H, draw_right_wall)
        make_page(pdf, "LEFT SHORT WALL", "Camera hole", EXT_W, BODY_H, draw_left_wall)
    print(f"Saved {out}")

if __name__ == "__main__":
    main()

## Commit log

2026-05-25 Initial parametric enclosure model
    FreeCAD Python model (cad/enclosure.py + cad/params.py) for a compact
    telemetry enclosure housing RPi 4B, RFD900A, Quectel EG25-G + Mini PCIe
    USB adapter, and Adafruit DS3231 RTC.
    - 116 x 86 x 60.5 mm external (body + lid)
    - Pi 4B in +X/-Y corner, M2.5 standoffs, I/O cutouts on two walls
    - Quectel adapter on upper shelf with 4x M3 screw posts (correct 88.9x44.96x18.03 mm dims)
    - RFD900A adhesive-mounted to left interior wall (no PCB holes)
    - 5 antenna holes on lid (3 LTE + 2 RFD900A), snap-fit lip, 4-corner screws
    - Vent slots on lid and long side walls
    - Exports: STEP + STL for body and lid, assembly FCStd with reference bricks
    - FreeCAD MCP bridge wired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
    [enclosure_body.FCStd, enclosure_body.step, enclosure_body.stl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]
2026-05-25 Move Quectel to back wall, antenna holes to side walls
    - Quectel Mini PCIe adapter: removed floor-standing posts (clashed with
    Pi standoffs); now mounts on 4 x M3 bosses on the back wall interior
    face (QU_WALL_X0_INT=10, QU_WALL_Z0_INT=8, 3mm standoffs, 8mm pilots).
    7.5mm Y gap to Pi edge, 2mm Z headroom under lid.
    - RFD900A: already adhesive-mounted to left short wall; removed
    shelf rail remnant entirely.
    - Antenna holes moved from lid to walls:
    3 x LTE on back long wall at X=[8,26,44] world, Z=30.5mm
    2 x RFD on left short wall at Y=[34,52] world, Z=30.5mm
    Lid is now a clean plate (snap lip + corner screws + vent slots only).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
    [enclosure_body.FCStd, enclosure_body.step, enclosure_body.stl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]
2026-05-25 Remove RTC platform, consolidate antenna holes, move GPIO slot
    - Remove Adafruit RTC clip-down pad and posts; RTC now mounts on Pi GPIO pins.
    - All 5 antenna holes moved to the left short wall (X=0):
    Y = 15, 29, 43, 57, 71 mm (14 mm spacing, 11.5 mm edge margins)
    Z = 30.5 mm world — same height, 11.5 mm below vent slots
    First 3 = LTE (Quectel), last 2 = RFD (RFD900A)
    - GPIO wire pass-through relocated from back long wall to right short wall
    (X=INT_L), below the Pi network/USB cutout, at Z = 8.5 mm world.
    [enclosure_body.FCStd, enclosure_body.step, enclosure_body.stl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]
2026-05-25 Rearrange left wall: LTE/RFD vertical stacks + CAN port
    Left short wall (X=0) now has three distinct zones:
    - Back corner (Y=74mm): 3 LTE holes, vertically stacked at Z=15, 30, 45mm
    - Front corner (Y=10mm): 2 RFD900A SMA holes, 20mm c-c at Z=18.75, 38.75mm
    - Centre (Y=43mm): 1x 20mm CAN port hole at Z=28.75mm
    [enclosure_body.FCStd, enclosure_body.step, enclosure_body.stl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]
2026-05-25 Add turntable GIF preview, component PDF, and render script
    - exports/enclosure_preview.gif: 40-frame animated turntable (cad/render_gif.py)
    - Embed GIF at top of README.md for instant GitHub preview
    - Add telem-enclosure-components.pdf (component datasheets / spec reference)
    - Add cad/render_gif.py: reproducible renderer using matplotlib + numpy-stl
    - Update .gitignore to exclude tools/render-venv/
    - Fix stale RTC and Quectel mounting notes in README component table
    [render_gif.py]
2026-05-25 Add 1:1 scale face-template PDF for physical component fit-checking
    - cad/face_templates.py: generates exports/face_templates.pdf (5 pages)
    - Each page is a true 1:1 orthographic projection of one enclosure face
    - Pages: floor plan, right short wall, left short wall, front long wall,
    back long wall (interior face)
    - Shows Pi standoff holes, IO cutouts, antenna holes, Quectel boss positions
    - Dimension callouts, 30mm scale bar, and print-at-100% warning on every page
    - Regenerate with: tools/render-venv/bin/python cad/face_templates.py
    [face_templates.py]
2026-06-09 Reorganize exports by car version and add car-1.5 CAD workflow
    - Split exports into car-1.5/ (recovered SolidWorks STEP) and car-2/ (parametric)
    - Add import_legacy.py, axis-based feature extraction, and car-1.5 face templates
    - Fix face-template hole classification (axis direction + exterior wall snapping)
    - Update render_gif, face_templates, and enclosure.py for versioned export paths
    [SoftwareEnclosureBottomCar1.5.STEP, SoftwareEnclosureTopCar1.5.STEP, enclosure_body.FCStd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]
2026-06-09 Remove car-1.5 face templates and related extraction scripts
    Drop the inaccurate car-1.5 PDF blueprint and its custom generator/extractor
    scripts; car-1.5 CAD assets remain in exports/car-1.5/.
2026-06-14 Reset car-2 exports from car-1.5 baseline with smooth interior floor.
    Copy the legacy enclosure into car-2, remove rectangular floor cutouts while keeping Pi mounting holes, and refresh the README preview GIF.
    [enclosure_body.FCStd, enclosure_body.step, enclosure_body.stl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]
2026-06-14 Update READMEs to reflect car-2 as the active legacy-based redesign.
    Document car-2 as the working 228.6 mm export folder, car-1.5 as the archive baseline, and the correct GIF/MCP workflow.
2026-06-20 Add STL web viewer and sync car-2 smooth-floor exports.
    Introduces a lightweight Three.js viewer with face IDs for AI-assisted edits,
    documents the Cursor workflow, and regenerates car-2 body/assembly assets plus the preview GIF.
    [enclosure_body.FCStd, enclosure_body.step, enclosure_body.stl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]
2026-06-20 Update enclosure and lid to car-2 specs with DXF and blueprints
    [enclosure_body.FCStd, enclosure_body.step, enclosure_body.stl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]
2026-06-20 Shorten radio slot guide walls to half length and shift radio slot 10mm left to clear floor hole
    [enclosure_body.FCStd, enclosure_body.step, enclosure_body.stl]
2026-07-12 feat: redesign enclosure (thinned walls, swapped features, relocated LTE bosses, added 10mm height)
    [enclosure_body.FCStd, enclosure_body.step, enclosure_body.stl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]
2026-07-12 fix: elevate bosses/holes, rotate STLs for Y-up viewers, center readme gif
    [enclosure_body.FCStd, enclosure_body.step, enclosure_body.stl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]
2026-07-12 fix: align lid to Y-up and repair GIF render glitches
    [enclosure_body.stl, enclosure_body_head.stl, enclosure_lid.FCStd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]
